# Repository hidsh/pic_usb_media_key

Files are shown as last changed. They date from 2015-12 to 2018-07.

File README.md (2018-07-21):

# pic_usb_media_key

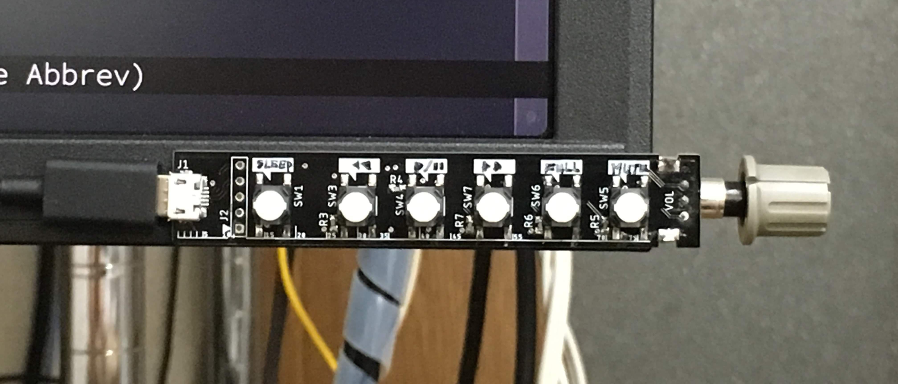
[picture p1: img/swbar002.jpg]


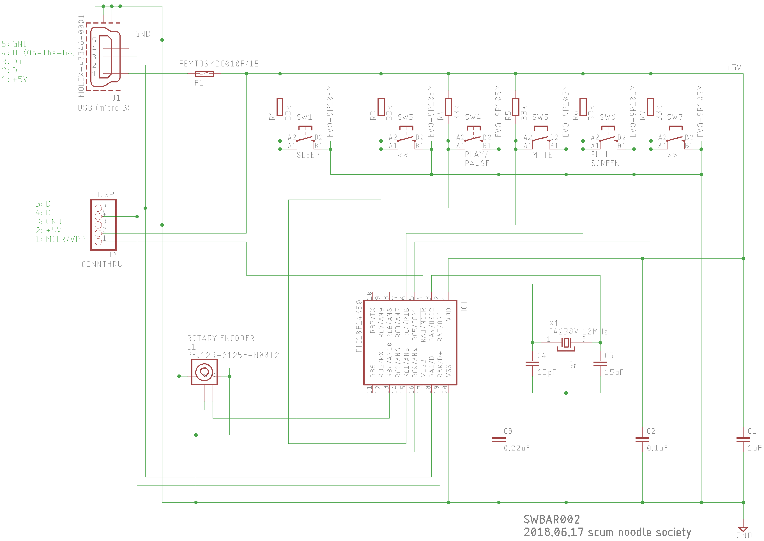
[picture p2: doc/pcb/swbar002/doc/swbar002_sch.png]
schematic


- IDE: MPLAB X v4.15
- compiler: C18 v3.46

## variant

### branch: hp_dso_pad

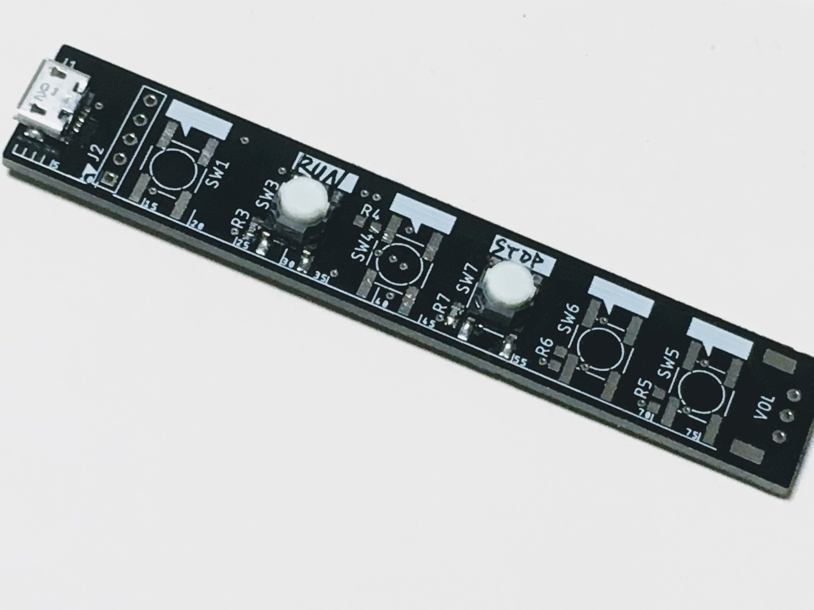
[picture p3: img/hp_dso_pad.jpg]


A quickfix for `RUN` and `STOP` buttons for DSOs [Agilent MSO8064A](https://www.keysight.com/en/pd-718231-pn-MSO8064A/infiniium-mixed-signal-oscilloscope-600-mhz-4-scope-and-16-digital-channels/).

## reference design

- [AE-PIC18F14K50](http://akizukidenshi.com/download/ds/akizuki/AE-PIC18F14K50.pdf)

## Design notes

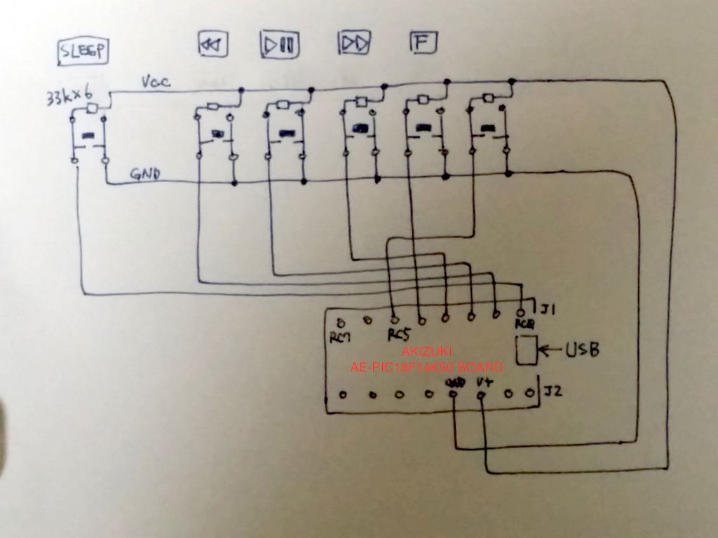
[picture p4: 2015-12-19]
doc/schematic.jpg

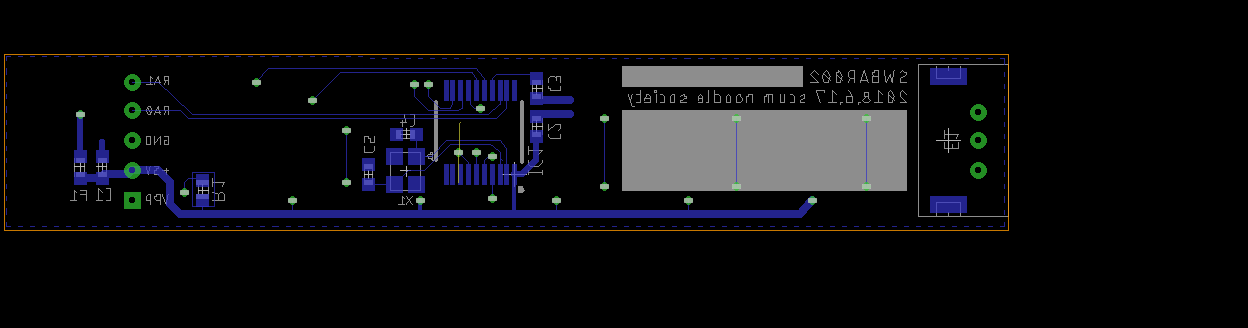
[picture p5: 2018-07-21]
doc/pcb/swbar002/doc/swbar002_brd_bottom.png

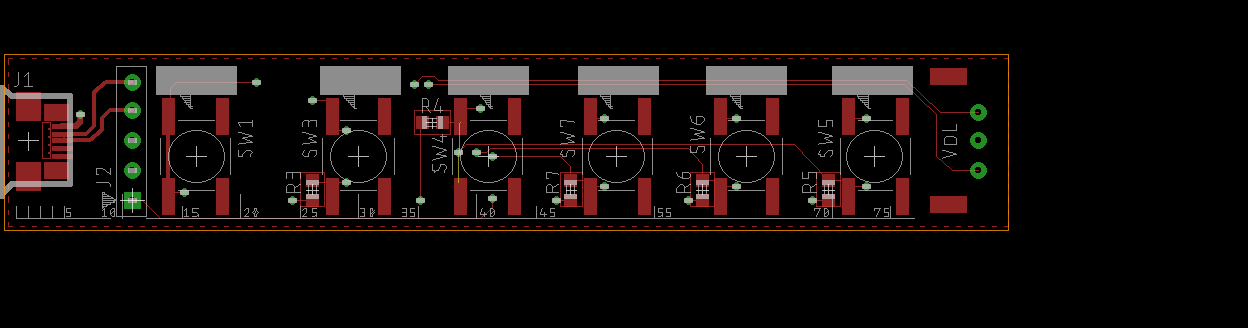
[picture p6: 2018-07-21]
doc/pcb/swbar002/doc/swbar002_brd_top.png

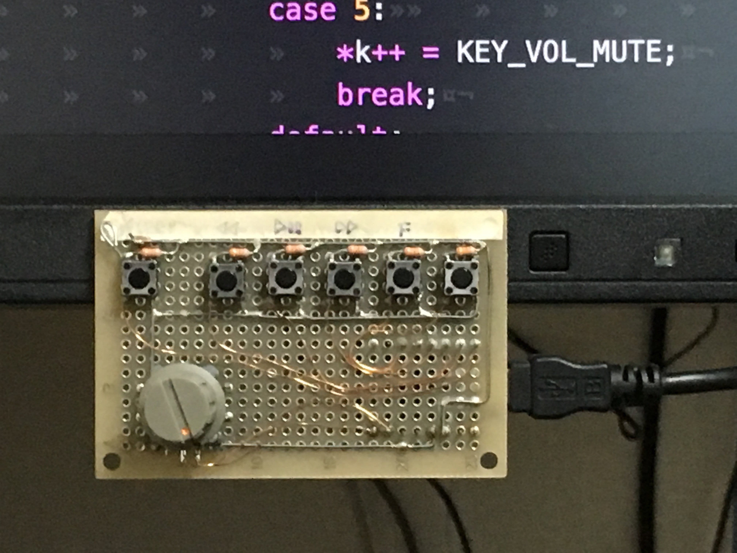
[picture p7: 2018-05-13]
doc/photo.jpg

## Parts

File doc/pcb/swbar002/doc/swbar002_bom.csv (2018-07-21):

Part | Value | Device | Package | Description
C1 | 1uF | C-EUC0603K | C0603K | CAPACITOR, European symbol
C2 | 0.1uF | C-EUC0603K | C0603K | CAPACITOR, European symbol
C3 | 0.22uF | C-EUC0603K | C0603K | CAPACITOR, European symbol
C4 | 15pF | C-EUC0603K | C0603K | CAPACITOR, European symbol
C5 | 15pF | C-EUC0603K | C0603K | CAPACITOR, European symbol
E1 | PEC12R-2125F-N0012 | PEC12R-2125F-N0012 | PEC12R | PEC12R-2125F-N0012,
F1 | FEMTOSMDC010F/15 | FEMTOSMDC010F/15 | C0603K | Resettable Fuse
IC1 | PIC18F14K50 | PIC18F14K50 | SSOP20
J1 | MOLEX-47346-0001 | MOLEX-47346-0001 | MOLEX-47364-0001 | MICRO USB B, BOTTOM MOUNT
J2 | CONNTHRU | PINHD-1X51X05_CONNTHRU | 1X05_CONNTHRU | PIN HEADER
R1 | 33k | R-EU_R0603 | R0603 | RESISTOR, European symbol
R3 | 33k | R-EU_R0603 | R0603 | RESISTOR, European symbol
R4 | 33k | R-EU_R0603 | R0603 | RESISTOR, European symbol
R5 | 33k | R-EU_R0603 | R0603 | RESISTOR, European symbol
R6 | 33k | R-EU_R0603 | R0603 | RESISTOR, European symbol
R7 | 33k | R-EU_R0603 | R0603 | RESISTOR, European symbol
SW1 | EVQ-9P105M | EVQ-9P105M | EVQ9P | Panasonic Tactile Switch
SW3 | EVQ-9P105M | EVQ-9P105M | EVQ9P | Panasonic Tactile Switch
SW4 | EVQ-9P105M | EVQ-9P105M | EVQ9P | Panasonic Tactile Switch
SW5 | EVQ-9P105M | EVQ-9P105M | EVQ9P | Panasonic Tactile Switch
SW6 | EVQ-9P105M | EVQ-9P105M | EVQ9P | Panasonic Tactile Switch
SW7 | EVQ-9P105M | EVQ-9P105M | EVQ9P | Panasonic Tactile Switch
X1 | FA238V 12MHz | FA-238V | XTAL_SMD_32X25 | EPSON TOYOCOM FA238V, SMD, 4 PAD

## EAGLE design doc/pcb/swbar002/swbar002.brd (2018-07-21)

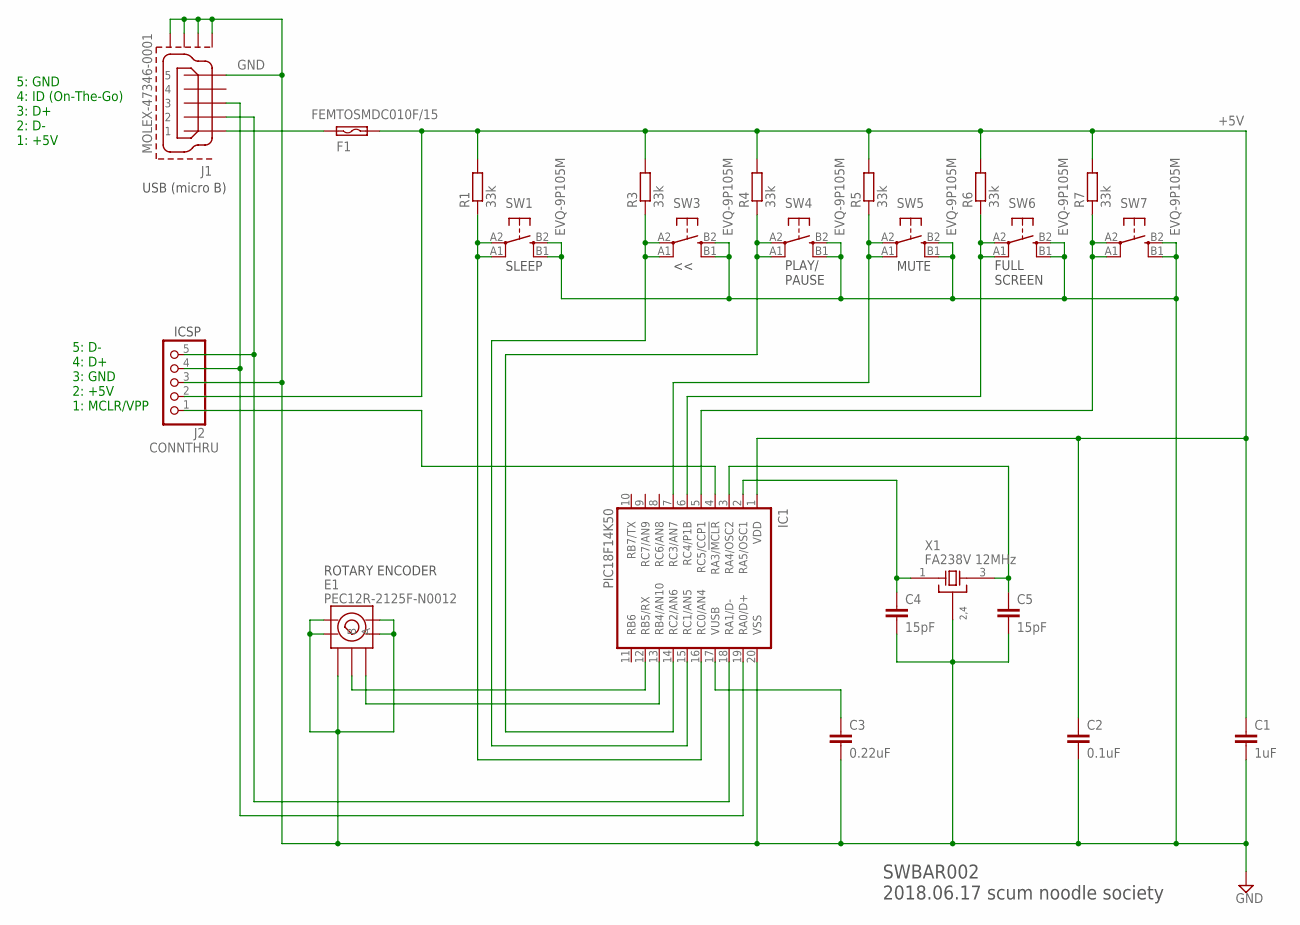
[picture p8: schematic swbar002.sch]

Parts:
C1: 1uF; C0603K
C2: 0.1uF; C0603K
C3: 0.22uF; C0603K
C4, C5: 15pF; C0603K
E1: PEC12R-2125F-N0012; PEC12R
F1: FEMTOSMDC010F/15; C0603K
IC1: PIC18F14K50; SSOP20
J1: MOLEX-47346-0001; MOLEX-47364-0001
J2: CONNTHRU; 1X05_CONNTHRU
R1, R3, R4, R5, R6, R7: 33k; R0603
SW1, SW3, SW4, SW5, SW6, SW7: EVQ-9P105M; EVQ9P
X1: FA238V 12MHz; XTAL_SMD_32X25

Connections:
+5V: C1.1, C2.1, F1.2, IC1.1 (VDD), J2.2, R1.2, R3.2, R4.2, R5.2, R6.2, R7.2
D+: IC1.19 (RA0/D+), J1.3, J2.4
D-: IC1.18 (RA1/D-), J1.2, J2.5
GND: C1.2, C2.2, C3.2, C4.2, C5.2, E1.GND@1 (GND), E1.GND@2 (GND), E1.GND@3 (GND), E1.GND@4 (GND), E1.GND@5 (GND), IC1.20 (VSS), J1.5, J1.GND1 (GND), J1.GND2 (GND), J1.GND3 (GND), J1.GND4 (GND), J2.3, SW1.B1 (G$S1), SW1.B2 (G$S2), SW3.B1 (G$S1), SW3.B2 (G$S2), SW4.B1 (G$S1), SW4.B2 (G$S2), SW5.B1 (G$S1), SW5.B2 (G$S2), SW6.B1 (G$S1), SW6.B2 (G$S2), SW7.B1 (G$S1), SW7.B2 (G$S2), X1.2 (GND), X1.4 (GND)
unnamed: IC1.16 (RC0/AN4), R1.1, SW1.A1 (G$P1), SW1.A2 (G$P2)
unnamed: E1.A, IC1.13 (RB4/AN10)
unnamed: IC1.5 (RC5/CCP1), R7.1, SW7.A1 (G$P1), SW7.A2 (G$P2)
unnamed: IC1.6 (RC4/P1B), R6.1, SW6.A1 (G$P1), SW6.A2 (G$P2)
unnamed: E1.B, IC1.12 (RB5/RX)
unnamed: IC1.7 (RC3/AN7), R5.1, SW5.A1 (G$P1), SW5.A2 (G$P2)
unnamed: IC1.14 (RC2/AN6), R4.1, SW4.A1 (G$P1), SW4.A2 (G$P2)
unnamed: IC1.4 (RA3/!MCLR!), J2.1
unnamed: IC1.15 (RC1/AN5), R3.1, SW3.A1 (G$P1), SW3.A2 (G$P2)
unnamed: C3.1, IC1.17 (VUSB)
unnamed: C5.1, IC1.3 (RA4/OSC2), X1.3 (X3)
unnamed: C4.1, IC1.2 (RA5/OSC1), X1.1 (X1)
VBUS: F1.1, J1.1

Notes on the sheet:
SLEEP
FULL SCREEN
MUTE
PLAY/ PAUSE
SWBAR002 2018.06.17 scum noodle society
5: GND 4: ID (On-The-Go) 3: D+ 2: D- 1: +5V
5: D- 4: D+ 3: GND 2: +5V 1: MCLR/VPP
USB (micro B)
ROTARY ENCODER
ICSP

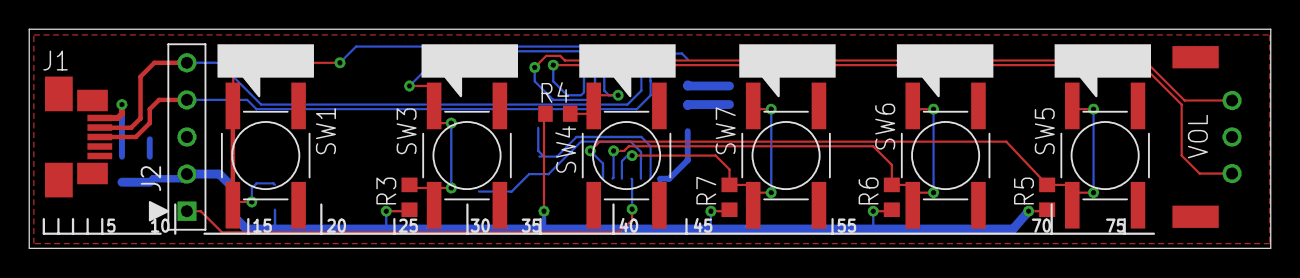
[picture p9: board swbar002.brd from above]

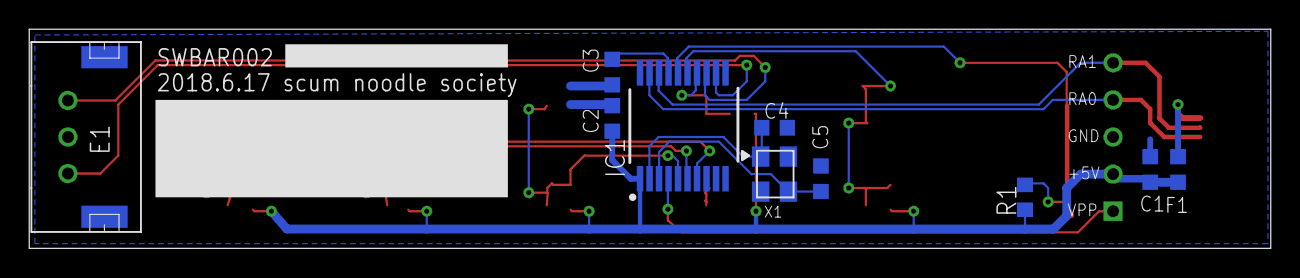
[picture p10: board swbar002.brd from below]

Board: 2 copper layers, 85.0 x 15.0 mm, 23 parts (10 on the bottom side), 17 nets.

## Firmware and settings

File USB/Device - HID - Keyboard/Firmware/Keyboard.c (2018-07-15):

/********************************************************************
 FileName:		Keyboard.c
 Dependencies:  See INCLUDES section
 Processor:     PIC18, PIC24, dsPIC, and PIC32 USB Microcontrollers
 Hardware:      This demo is natively intended to be used on Microchip USB demo
				boards supported by the MCHPFSUSB stack.  See release notes for
				support matrix.  This demo can be modified for use on other hardware
				platforms.
 Complier:      Microchip C18 (for PIC18), XC16 (for PIC24/dsPIC), XC32 (for PIC32)
 Company:       Microchip Technology, Inc.

 Software License Agreement:

 The software supplied herewith by Microchip Technology Incorporated
 (the "Company") for its PIC(R) Microcontroller is intended and
 supplied to you, the Company's customer, for use solely and
 exclusively on Microchip PIC Microcontroller products. The
 software is owned by the Company and/or its supplier, and is
 protected under applicable copyright laws. All rights are reserved.
 Any use in violation of the foregoing restrictions may subject the
 user to criminal sanctions under applicable laws, as well as to
 civil liability for the breach of the terms and conditions of this
 license.

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
********************************************************************
 File Description:

 Change History:
  Rev   Description
  ----  -----------------------------------------
  1.0   Initial release
  2.1   Updated for simplicity and to use common
					 coding style
  2.8   Improvements to USBCBSendResume(), to make it easier to use.
  2.9   Added remote wakeup capability to the demo.
  2.9f  Adding new part support
********************************************************************/

#ifndef KEYBOARD_C
#define KEYBOARD_C

/** INCLUDES *******************************************************/
#include "./USB/usb.h"
#include "HardwareProfile.h"
#include "./USB/usb_function_hid.h"
#include "kbd_usage.h"

/** CONFIGURATION **************************************************/
#if defined(LOW_PIN_COUNT_USB_DEVELOPMENT_KIT)
		#pragma config CPUDIV = NOCLKDIV
		#pragma config USBDIV = OFF
		#pragma config FOSC   = HS
		#pragma config PLLEN  = ON
		#pragma config FCMEN  = OFF
		#pragma config IESO   = OFF
		#pragma config PWRTEN = OFF
		#pragma config BOREN  = OFF
		#pragma config BORV   = 30
		#pragma config WDTEN  = OFF
		#pragma config WDTPS  = 32768
		#pragma config MCLRE  = OFF
		#pragma config HFOFST = OFF
		#pragma config STVREN = ON
		#pragma config LVP    = OFF
		#pragma config XINST  = OFF
		#pragma config BBSIZ  = OFF
		#pragma config CP0    = OFF
		#pragma config CP1    = OFF
		#pragma config CPB    = OFF
		#pragma config WRT0   = OFF
		#pragma config WRT1   = OFF
		#pragma config WRTB   = OFF
		#pragma config WRTC   = OFF
		#pragma config EBTR0  = OFF
		#pragma config EBTR1  = OFF
		#pragma config EBTRB  = OFF        
#else
	#error No hardware board defined, see "HardwareProfile.h" and __FILE__
#endif




/** VARIABLES ******************************************************/
#if defined(__18CXX)
	#pragma udata

	//The ReceivedDataBuffer[] and ToSendDataBuffer[] arrays are used as
	//USB packet buffers in this firmware.  Therefore, they must be located in
	//a USB module accessible portion of microcontroller RAM.
	#if defined(__18F14K50) || defined(__18F13K50) || defined(__18LF14K50) || defined(__18LF13K50)
		#pragma udata USB_VARIABLES=0x260
	#else
		#pragma udata
	#endif

#if 1
	#define IN_DATA_BUFFER_ADDRESS_TAG
	#define OUT_DATA_BUFFER_ADDRESS_TAG
#endif

unsigned char hid_report_in[HID_INT_IN_EP_SIZE] IN_DATA_BUFFER_ADDRESS_TAG;
volatile unsigned char hid_report_out[HID_INT_OUT_EP_SIZE] OUT_DATA_BUFFER_ADDRESS_TAG;

#if defined(__18CXX)
#pragma udata
#endif

#if defined(__18CXX)
	#pragma udata
#endif

#define SW_MAX      6
#define SW_RELEASE  1
#define SW_PRESS    0

typedef enum {ROT_NA, ROT_FF, ROT_RW} eROT_DIR;
eROT_DIR rot, rot_old;

BYTE read_sw;				// read switch
BYTE report[8];				// HID report TX buffer

typedef enum {
	SW_STAT_INIT = 0,
	SW_STAT_KEEP,
	SW_STAT_RELEASE
} eSW_STAT;

typedef struct {
	eSW_STAT	stat;
	WORD		hold_cnt;
	WORD		hold_max;
} sSW_DATA;

sSW_DATA sw_data[SW_MAX] = {
	{SW_STAT_INIT, 0, 800}, 	// 0: sleep
	{SW_STAT_INIT, 0, 60},	 	// 1: backward
	{SW_STAT_INIT, 0, 60}, 		// 2: play/pause
	{SW_STAT_INIT, 0, 60}, 		// 3: forward
	{SW_STAT_INIT, 0, 60}, 		// 4: full screen
	{SW_STAT_INIT, 0, 60} 		// 5: mute
}; 

USB_HANDLE lastINTransmission;
USB_HANDLE lastOUTTransmission;

#if 0
BOOL BlinkStatusValid;
DWORD CountdownTimerToShowUSBStatusOnLEDs;
#endif

/** PRIVATE PROTOTYPES *********************************************/
static void InitializeSystem(void);
void ProcessIO(void);
void UserInit(void);
void YourHighPriorityISRCode();
void YourLowPriorityISRCode();
void USBCBSendResume(void);
void Keyboard(void);

void USBHIDCBSetReportComplete(void);

void read_rotary_encoder(void);

/** VECTOR REMAPPING ***********************************************/
#if defined(__18CXX)
	//On PIC18 devices, addresses 0x00, 0x08, and 0x18 are used for
	//the reset, high priority interrupt, and low priority interrupt
	//vectors.  However, the current Microchip USB bootloader 
	//examples are intended to occupy addresses 0x00-0x7FF or
	//0x00-0xFFF depending on which bootloader is used.  Therefore,
	//the bootloader code remaps these vectors to new locations
	//as indicated below.  This remapping is only necessary if you
	//wish to program the hex file generated from this project with
	//the USB bootloader.  If no bootloader is used, edit the
	//usb_config.h file and comment out the following defines:
	//#define PROGRAMMABLE_WITH_USB_HID_BOOTLOADER
	//#define PROGRAMMABLE_WITH_USB_LEGACY_CUSTOM_CLASS_BOOTLOADER
	
	#if defined(PROGRAMMABLE_WITH_USB_HID_BOOTLOADER)
		#define REMAPPED_RESET_VECTOR_ADDRESS			0x1000
		#define REMAPPED_HIGH_INTERRUPT_VECTOR_ADDRESS	0x1008
		#define REMAPPED_LOW_INTERRUPT_VECTOR_ADDRESS	0x1018
	#elif defined(PROGRAMMABLE_WITH_USB_MCHPUSB_BOOTLOADER)	
		#define REMAPPED_RESET_VECTOR_ADDRESS			0x800
		#define REMAPPED_HIGH_INTERRUPT_VECTOR_ADDRESS	0x808
		#define REMAPPED_LOW_INTERRUPT_VECTOR_ADDRESS	0x818
	#else	
		#define REMAPPED_RESET_VECTOR_ADDRESS			0x00
		#define REMAPPED_HIGH_INTERRUPT_VECTOR_ADDRESS	0x08
		#define REMAPPED_LOW_INTERRUPT_VECTOR_ADDRESS	0x18
	#endif
	
	#if defined(PROGRAMMABLE_WITH_USB_HID_BOOTLOADER)||defined(PROGRAMMABLE_WITH_USB_MCHPUSB_BOOTLOADER)
	extern void _startup (void);        // See c018i.c in your C18 compiler dir
	#pragma code REMAPPED_RESET_VECTOR = REMAPPED_RESET_VECTOR_ADDRESS
	void _reset (void)
	{
		_asm goto _startup _endasm
	}
	#endif
	#pragma code REMAPPED_HIGH_INTERRUPT_VECTOR = REMAPPED_HIGH_INTERRUPT_VECTOR_ADDRESS
	void Remapped_High_ISR (void)
	{
		 _asm goto YourHighPriorityISRCode _endasm
	}
	#pragma code REMAPPED_LOW_INTERRUPT_VECTOR = REMAPPED_LOW_INTERRUPT_VECTOR_ADDRESS
	void Remapped_Low_ISR (void)
	{
		 _asm goto YourLowPriorityISRCode _endasm
	}
	
	#if defined(PROGRAMMABLE_WITH_USB_HID_BOOTLOADER)||defined(PROGRAMMABLE_WITH_USB_MCHPUSB_BOOTLOADER)
	//Note: If this project is built while one of the bootloaders has
	//been defined, but then the output hex file is not programmed with
	//the bootloader, addresses 0x08 and 0x18 would end up programmed with 0xFFFF.
	//As a result, if an actual interrupt was enabled and occured, the PC would jump
	//to 0x08 (or 0x18) and would begin executing "0xFFFF" (unprogrammed space).  This
	//executes as nop instructions, but the PC would eventually reach the REMAPPED_RESET_VECTOR_ADDRESS
	//(0x1000 or 0x800, depending upon bootloader), and would execute the "goto _startup".  This
	//would effective reset the application.
	
	//To fix this situation, we should always deliberately place a 
	//"goto REMAPPED_HIGH_INTERRUPT_VECTOR_ADDRESS" at address 0x08, and a
	//"goto REMAPPED_LOW_INTERRUPT_VECTOR_ADDRESS" at address 0x18.  When the output
	//hex file of this project is programmed with the bootloader, these sections do not
	//get bootloaded (as they overlap the bootloader space).  If the output hex file is not
	//programmed using the bootloader, then the below goto instructions do get programmed,
	//and the hex file still works like normal.  The below section is only required to fix this
	//scenario.
	#pragma code HIGH_INTERRUPT_VECTOR = 0x08
	void High_ISR (void)
	{
		 _asm goto REMAPPED_HIGH_INTERRUPT_VECTOR_ADDRESS _endasm
	}
	#pragma code LOW_INTERRUPT_VECTOR = 0x18
	void Low_ISR (void)
	{
		 _asm goto REMAPPED_LOW_INTERRUPT_VECTOR_ADDRESS _endasm
	}
	#endif	//end of "#if defined(PROGRAMMABLE_WITH_USB_HID_BOOTLOADER)||defined(PROGRAMMABLE_WITH_USB_LEGACY_CUSTOM_CLASS_BOOTLOADER)"

	#pragma code
	
	
	//These are your actual interrupt handling routines.
	#pragma interrupt YourHighPriorityISRCode
	void YourHighPriorityISRCode()
	{
		//Check which interrupt flag caused the interrupt.
		//Service the interrupt
		//Clear the interrupt flag
		//Etc.
		#if defined(USB_INTERRUPT)
			USBDeviceTasks();
		#endif
	
		read_rotary_encoder();
	
	}	//This return will be a "retfie fast", since this is in a #pragma interrupt section 
	#pragma interruptlow YourLowPriorityISRCode
	void YourLowPriorityISRCode()
	{
		//Check which interrupt flag caused the interrupt.
		//Service the interrupt
		//Clear the interrupt flag
		//Etc.

	}	//This return will be a "retfie", since this is in a #pragma interruptlow section 

#elif defined(__C30__) || defined __XC16__
	#if defined(PROGRAMMABLE_WITH_USB_HID_BOOTLOADER)
		/*
		 *	ISR JUMP TABLE
		 *
		 *	It is necessary to define jump table as a function because C30 will
		 *	not store 24-bit wide values in program memory as variables.
		 *
		 *	This function should be stored at an address where the goto instructions 
		 *	line up with the remapped vectors from the bootloader's linker script.
		 *  
		 *  For more information about how to remap the interrupt vectors,
		 *  please refer to AN1157.  An example is provided below for the T2
		 *  interrupt with a bootloader ending at address 0x1400
		 */
       void __attribute__ ((address(0x1404))) ISRTable(){
       
       	asm("reset"); //reset instruction to prevent runaway code
       	asm("goto %0"::"i"(&_T2Interrupt));  //T2Interrupt's address
       }
	#endif
#elif defined(_PIC14E)
		//These are your actual interrupt handling routines.
	void interrupt ISRCode()
	{
		//Check which interrupt flag caused the interrupt.
		//Service the interrupt
		//Clear the interrupt flag
		//Etc.
		#if defined(USB_INTERRUPT)

			USBDeviceTasks();
		#endif
	}
#endif

	/** DECLARATIONS ***************************************************/
#if defined(__18CXX)
	#pragma code
#endif

/********************************************************************
 * Function:        void main(void)
 *
 * PreCondition:    None
 *
 * Input:           None
 *
 * Output:          None
 *
 * Side Effects:    None
 *
 * Overview:        Main program entry point.
 *
 * Note:            None
 *******************************************************************/
void main(void)
{
	InitializeSystem();

	#if defined(USB_INTERRUPT)
		USBDeviceAttach();
	#endif

	while(1)
	{
		#if defined(USB_POLLING)
		// Check bus status and service USB interrupts.
		USBDeviceTasks(); // Interrupt or polling method.  If using polling, must call
						  // this function periodically.  This function will take care
						  // of processing and responding to SETUP transactions 
						  // (such as during the enumeration process when you first
						  // plug in).  USB hosts require that USB devices should accept
						  // and process SETUP packets in a timely fashion.  Therefore,
						  // when using polling, this function should be called 
						  // regularly (such as once every 1.8ms or faster** [see 
						  // inline code comments in usb_device.c for explanation when
						  // "or faster" applies])  In most cases, the USBDeviceTasks() 
						  // function does not take very long to execute (ex: <100 
						  // instruction cycles) before it returns.
		#endif
					  

		// Application-specific tasks.
		// Application related code may be added here, or in the ProcessIO() function.
		ProcessIO();        
	}//end while
}//end main


/********************************************************************
 * Function:        static void InitializeSystem(void)
 *
 * PreCondition:    None
 *
 * Input:           None
 *
 * Output:          None
 *
 * Side Effects:    None
 *
 * Overview:        InitializeSystem is a centralize initialization
 *                  routine. All required USB initialization routines
 *                  are called from here.
 *
 *                  User application initialization routine should
 *                  also be called from here.                  
 *
 * Note:            None
 *******************************************************************/
static void InitializeSystem(void)
{
	#if (defined(__18CXX) & !defined(PIC18F87J50_PIM) & !defined(PIC18F97J94_FAMILY))
		ADCON1 |= 0x0F;                 // Default all pins to digital
	#endif

//	The USB specifications require that USB peripheral devices must never source
//	current onto the Vbus pin.  Additionally, USB peripherals should not source
//	current on D+ or D- when the host/hub is not actively powering the Vbus line.
//	When designing a self powered (as opposed to bus powered) USB peripheral
//	device, the firmware should make sure not to turn on the USB module and D+
//	or D- pull up resistor unless Vbus is actively powered.  Therefore, the
//	firmware needs some means to detect when Vbus is being powered by the host.
//	A 5V tolerant I/O pin can be connected to Vbus (through a resistor), and
//	can be used to detect when Vbus is high (host actively powering), or low
//	(host is shut down or otherwise not supplying power).  The USB firmware
//	can then periodically poll this I/O pin to know when it is okay to turn on
//	the USB module/D+/D- pull up resistor.  When designing a purely bus powered
//	peripheral device, it is not possible to source current on D+ or D- when the
//	host is not actively providing power on Vbus. Therefore, implementing this
//	bus sense feature is optional.  This firmware can be made to use this bus
//	sense feature by making sure "USE_USB_BUS_SENSE_IO" has been defined in the
//	HardwareProfile.h file.    
	#if defined(USE_USB_BUS_SENSE_IO)
	tris_usb_bus_sense = INPUT_PIN; // See HardwareProfile.h
	#endif
	
//	If the host PC sends a GetStatus (device) request, the firmware must respond
//	and let the host know if the USB peripheral device is currently bus powered
//	or self powered.  See chapter 9 in the official USB specifications for details
//	regarding this request.  If the peripheral device is capable of being both
//	self and bus powered, it should not return a hard coded value for this request.
//	Instead, firmware should check if it is currently self or bus powered, and
//	respond accordingly.  If the hardware has been configured like demonstrated
//	on the PICDEM FS USB Demo Board, an I/O pin can be polled to determine the
//	currently selected power source.  On the PICDEM FS USB Demo Board, "RA2" 
//	is used for	this purpose.  If using this feature, make sure "USE_SELF_POWER_SENSE_IO"
//	has been defined in HardwareProfile - (platform).h, and that an appropriate I/O pin 
//	has been mapped	to it.
	#if defined(USE_SELF_POWER_SENSE_IO)
	tris_self_power = INPUT_PIN;	// See HardwareProfile.h
	#endif
	
	UserInit();

	USBDeviceInit();	//usb_device.c.  Initializes USB module SFRs and firmware
						//variables to known states.
}//end InitializeSystem


/******************************************************************************
 * Function:        void UserInit(void)
 *
 * PreCondition:    None
 *
 * Input:           None
 *
 * Output:          None
 *
 * Side Effects:    None
 *
 * Overview:        This routine should take care of all of the demo code
 *                  initialization that is required.
 *
 * Note:            
 *
 *****************************************************************************/
void UserInit(void)
{
	//initialize the variable holding the handle for the last
	// transmission

	lastINTransmission = 0;
	lastOUTTransmission = 0;


#if __18F14K50
	// sw
	ANSEL  = 0b00000000;            // all digital
	ANSELH = 0b00000000;            // all digital
	TRISC  = 0b11111111;            // all input for sw

	// rotary encoder
	INTCON2bits.RABPU = 0;          // PORTB pull up all
	INTCONbits.RABIF  = 0;          // clear int flag
	INTCONbits.RABIE  = 1;          // enable int (input-change)
	IOCB = 0x30;                    // bit5..4 as input-change
	INTCONbits.GIE    = 1;          // enable global int
#endif
	rot     = ROT_NA;
	rot_old = ROT_NA;
}//end UserInit


/********************************************************************
 * Function:        void ProcessIO(void)
 *	
 * PreCondition:    None
 *
 * Input:           None
 *
 * Output:          None
 *
 * Side Effects:    None
 *
 * Overview:        This function is a place holder for other user
 *                  routines. It is a mixture of both USB and
 *                  non-USB tasks.
 *
 * Note:            None
 *******************************************************************/
void ProcessIO(void)
{   
#if 0
	//Blink the LEDs according to the USB device status
	//However, the LEDs are also used temporarily for showing the Num Lock 
	//keyboard LED status.  If the host sends an LED state update interrupt
	//out report, or sends it by a SET_REPORT control transfer, then
	//the demo board LEDs are temporarily taken over to show the Num Lock
	//LED state info.  After a countdown timout, the firmware will switch
	//back to showing the USB state on the LEDs, instead of the num lock status.
	if(BlinkStatusValid == TRUE)
	{
		BlinkUSBStatus();
	} else {
		CountdownTimerToShowUSBStatusOnLEDs--;
		if(CountdownTimerToShowUSBStatusOnLEDs == 0)
		{
			BlinkStatusValid = TRUE;
		}
	}
#endif

	read_sw = PORTC;
	
	//Check if we should assert a remote wakeup request to the USB host, when
	//the user presses the pushbutton.
	if((read_sw & 0x0b00111111) != 0b00111111) {		// press any sw
		USBCBSendResume();								//Does nothing unless we are in USB suspend with remote wakeup armed.
	}

	// User Application USB tasks
	if((USBDeviceState < CONFIGURED_STATE)||(USBSuspendControl==1)) return;

	//Check if the IN endpoint is not busy, and if it isn't check if we want to send
	//keystroke data to the host.
	if(HIDTxHandleBusy(lastINTransmission)) return;
	
	//Call the function that behaves like a keyboard  
 	Keyboard();        
	 
}//end ProcessIO

void read_rotary_encoder(void)
{
	static BYTE data = 0x00;
	BYTE enc;

	if(INTCONbits.RABIF == 0) return;
	INTCONbits.RABIF = 0;                   // clear int flag

    enc = PORTB & 0x30;                     // PORTB:00AB_0000
    data = ((data << 2) & 0xC0) | enc;        // enc  :oonn_0000
										//       ^  ^-- n:new value
										//       +----- o:old value
    switch (data) {
	case 0b11010000:                    // 3 -> 1
		rot = ROT_FF;
		break;
	case 0b01110000:                    // 1 -> 3
		rot = ROT_RW;
		break;
	default:
		break;
    }
}

void Keyboard(void)
{
	BOOL pressed;
	sSW_DATA *psw;
	BYTE i;
	BYTE *k;

	memset(report, 0, sizeof(report));				// HID report TX buffer
	k = &report[2];

	// rotary encoder
	if((rot == ROT_FF) && (rot_old == ROT_FF)) {
		*k = KEY_VOL_DOWN;
		rot = ROT_NA;
	}
	else if((rot == ROT_RW) & (rot_old == ROT_RW)) {
		*k = KEY_VOL_UP;
		rot = ROT_NA;
	}
    rot_old = rot;
    
    // switches
    for(i=0; i<SW_MAX; i++) {
        psw = &sw_data[i];
        pressed = (read_sw & (1 << i))? FALSE : TRUE;	// HI:released, LO:pressed
        switch(psw->stat) {
            case SW_STAT_INIT:
                if(pressed) {
                    if(psw->hold_cnt < psw->hold_max) {
                        psw->hold_cnt++;
                    }
                    else {
                        psw->hold_cnt = 0;
                        
                        if(i == 0) {					// SLEEP		(Mac: cmd + opt + F12)
                            report[0] |= (KEY_MOD_CMD_L | KEY_MOD_OPT_L);
                            *k++ = KEY_F12;
                        }
                        psw->stat = SW_STAT_KEEP;
                    }
                }
                break;
            case SW_STAT_KEEP:
                if(!pressed) {
                    psw->stat = SW_STAT_RELEASE;
                }
                break;
            case SW_STAT_RELEASE:
                psw->stat = SW_STAT_INIT;
                switch(i) {
                    case 0:								// SLEEP		(Mac: cmd + opt + F12)
                        memset(report, 0, sizeof(report));
                         break;
                    case 1:								// BACKWARD		(<<)
                        *k++ = KEY_LEFT;
                        break;
                    case 2:						   		// PLAY/PAUSE	(SPACE)
                        *k++ = KEY_SPACE;
                        break;
                    case 5:								// FORWARD		(>>)
                        *k++ = KEY_RIGHT;
                        break;
                    case 4:								// FULL SCREEN	(Mac: cmd + ctrl + F)
                        report[0] |= (KEY_MOD_GUI_L | KEY_MOD_CTL_L);
                        *k++ = KEY_F;
                        break;
                    case 3:								// MUTE
                        *k++ = KEY_VOL_MUTE;
                        break;
                    default:
                        break;
                }
                break;
            default:
                break;
        }
	}
	//Send the 8 byte packet over USB to the host.
	lastINTransmission = HIDTxPacket(HID_EP, report, 8);
}//end keyboard()
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

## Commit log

2018-06-22 improve unbouncing to read encoder, behavior of sleep sw
2018-07-15 correspond to new pcb(swbar002)
2018-07-21 add new pcb swbar002
    [swbar002.GBL, swbar002.GBO, swbar002.GBP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]
